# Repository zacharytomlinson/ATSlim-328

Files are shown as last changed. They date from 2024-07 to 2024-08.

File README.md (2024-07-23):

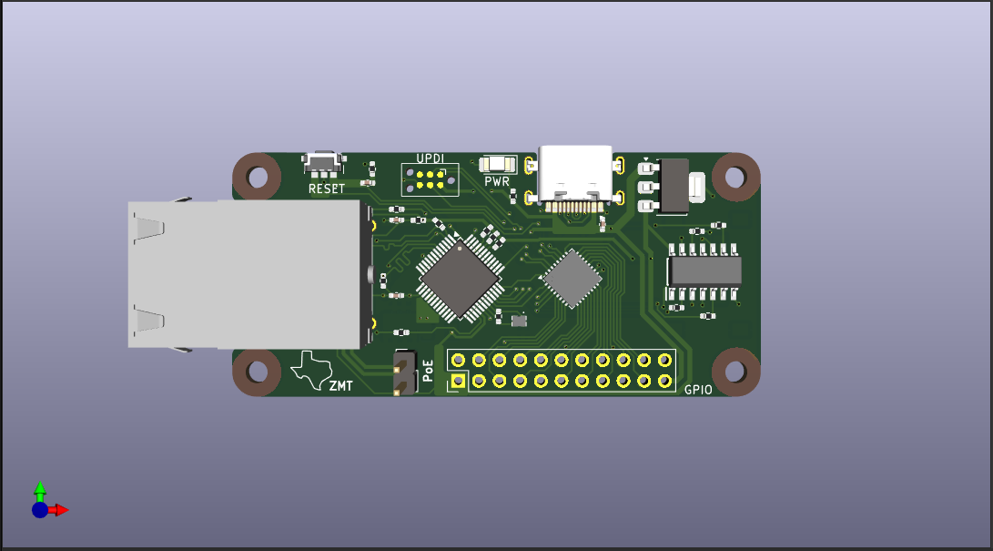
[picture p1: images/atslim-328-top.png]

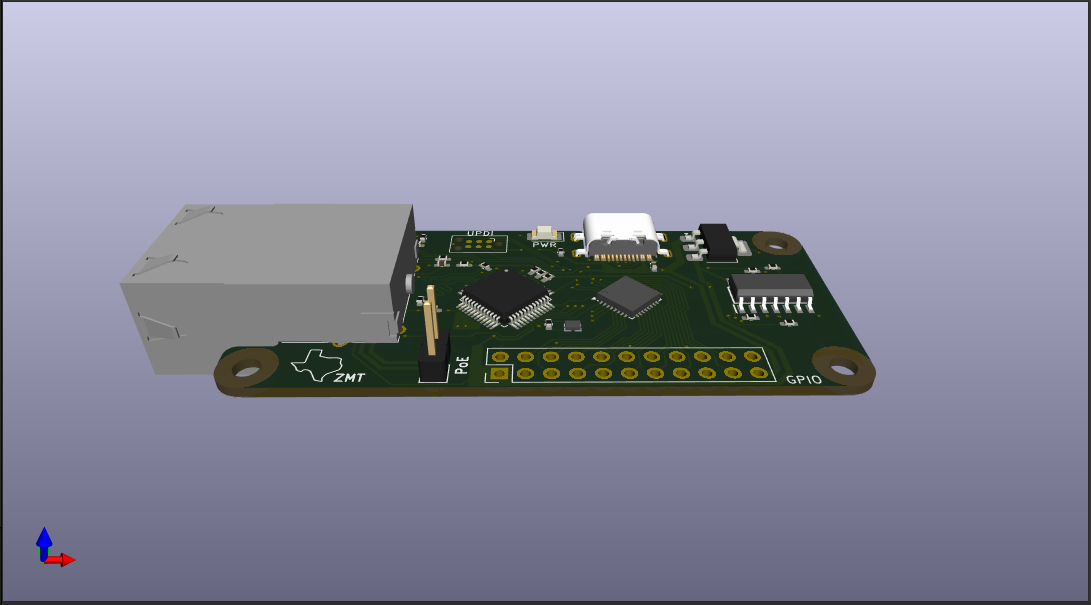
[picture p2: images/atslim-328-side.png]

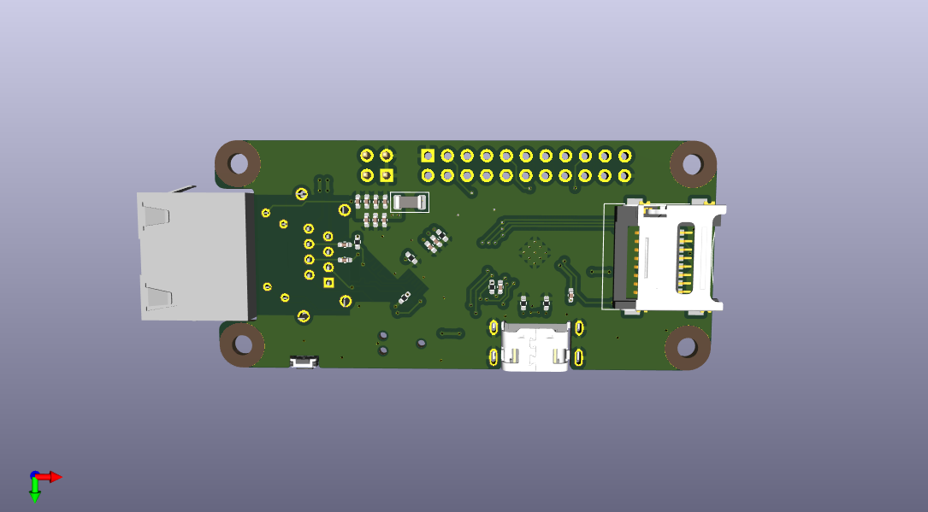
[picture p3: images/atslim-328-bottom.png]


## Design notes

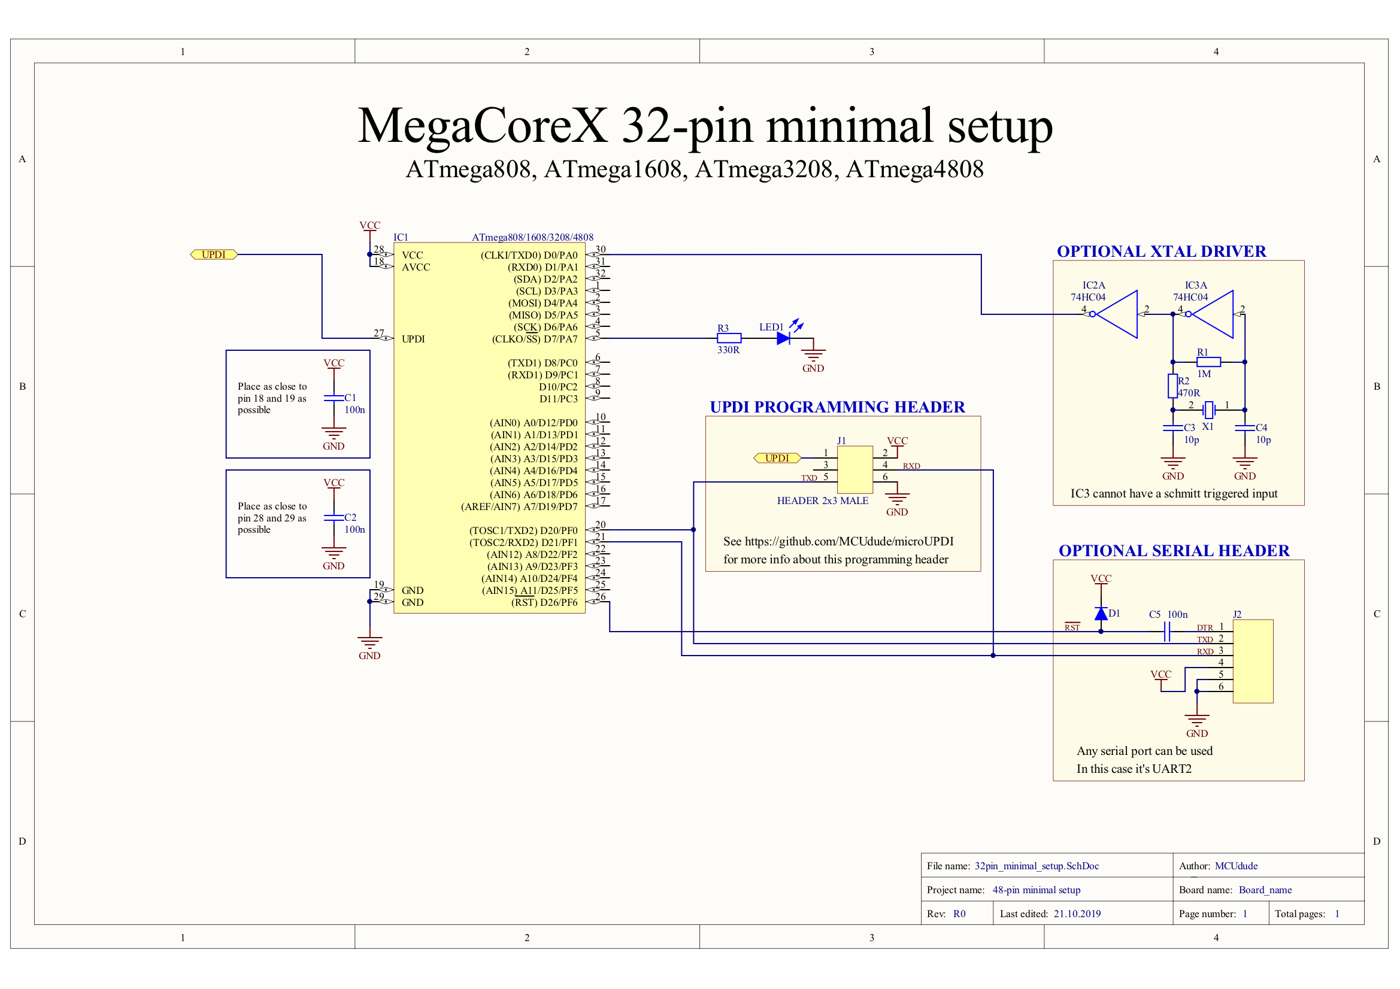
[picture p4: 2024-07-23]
fiducials/doc/3208PinDesc.png

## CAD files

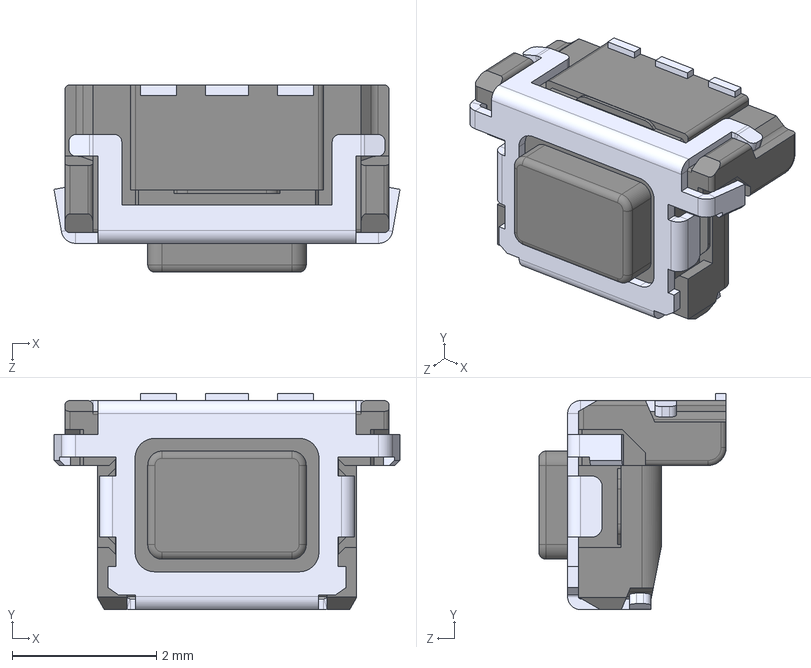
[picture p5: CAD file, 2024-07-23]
fiducials/3D/EVP-AEDB2A.step
4.80 x 3.00 x 2.60 mm

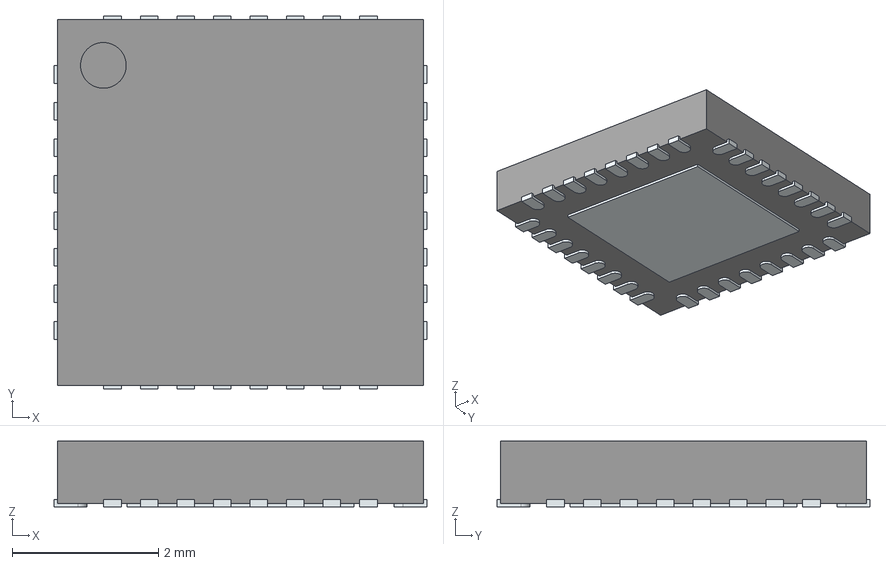
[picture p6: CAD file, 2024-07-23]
fiducials/3D/ATMEGA3208-MFR.stp
5.10 x 5.10 x 0.9 mm
ThermalPin
PinsArrayLR
PinsArrayTB

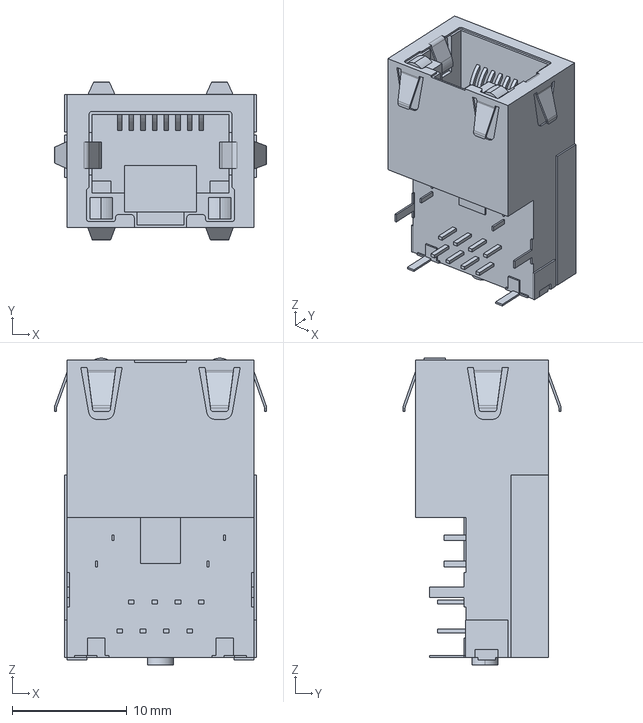
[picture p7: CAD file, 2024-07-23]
fiducials/3D/1888250-1.stp
18.5 x 13.8 x 26.7 mm

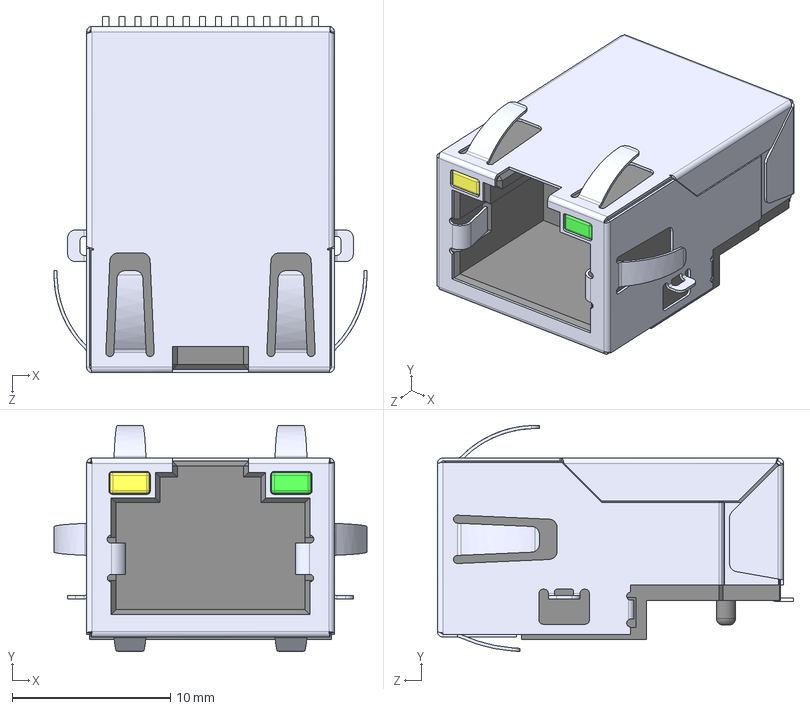
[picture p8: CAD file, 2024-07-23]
fiducials/3D/7498111120R.step
19.7 x 14.3 x 22.5 mm

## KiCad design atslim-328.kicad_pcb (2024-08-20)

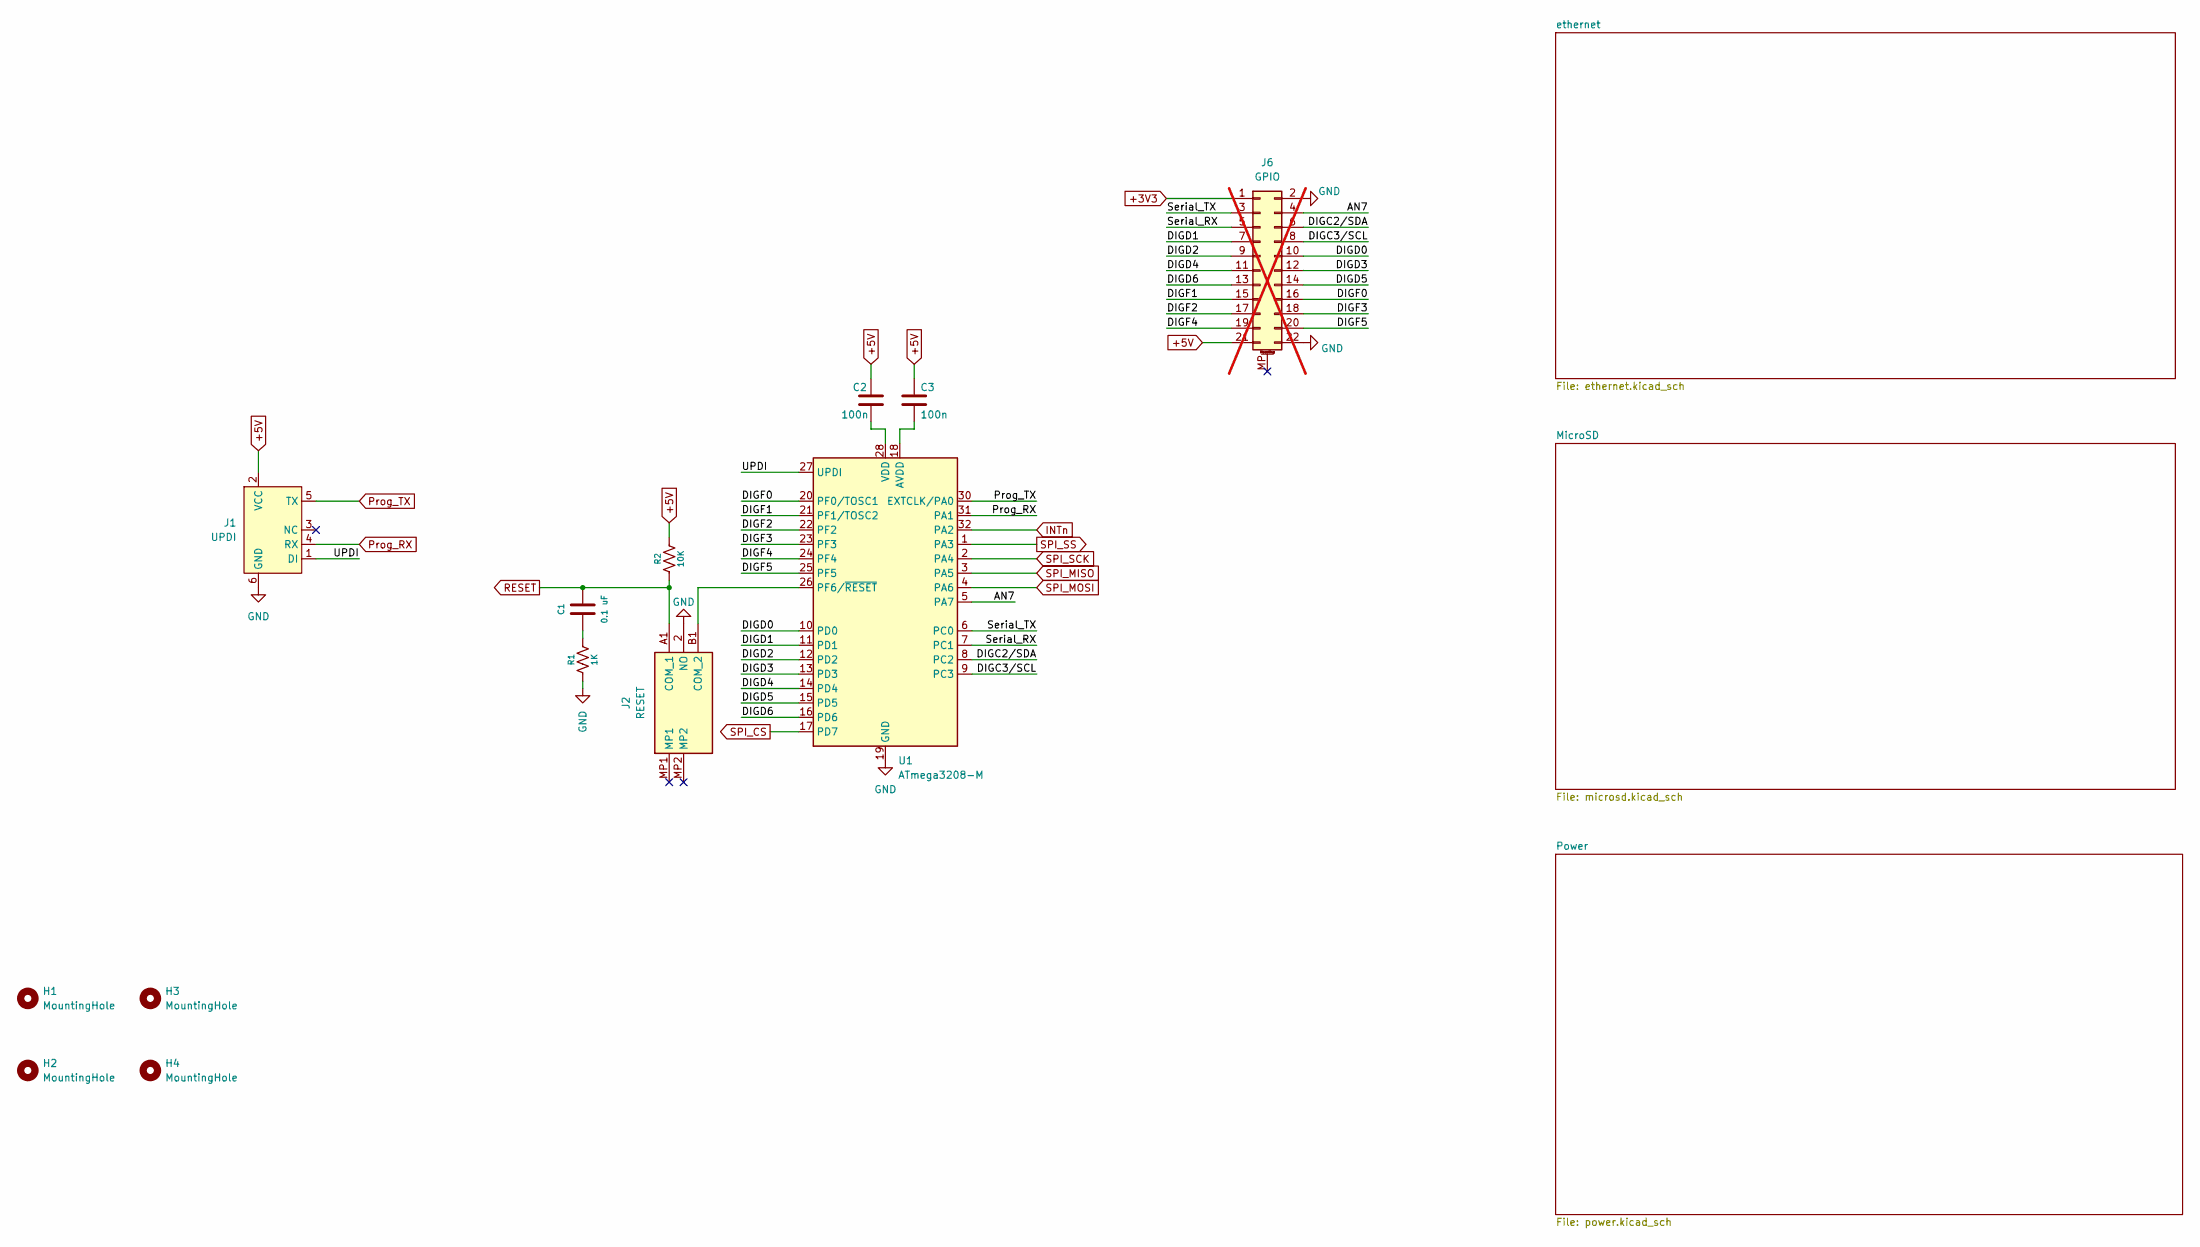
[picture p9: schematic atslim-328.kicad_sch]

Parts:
C1: 0.1 uF; C_0402_1005Metric_Pad0.74x0.62mm_HandSolder; MPN C0805C104K1RACAUTO
C2, C3: 100n; C_0402_1005Metric_Pad0.74x0.62mm_HandSolder
H1, H2, H3, H4: MountingHole; RPI_MountingHole
J1: UPDI; Tag-Connect_TC2030-IDC-NL_2x03_P1.27mm_Vertical
J2: RESET; EVPAEDB2A; Mouser Part Number 667-EVP-AEDB2A
J6: GPIO; PinHeader_2x11_P2.54mm_Vertical; not fitted
R1: 1K; R_0402_1005Metric_Pad0.72x0.64mm_HandSolder; MPN CRCW08051K00JNEA
R2: 10K; R_0402_1005Metric_Pad0.72x0.64mm_HandSolder; MPN CRCW080510K0JNEA
U1: ATmega3208-M; QFN-32-1EP_5x5mm_P0.5mm_EP3.1x3.1mm_ThermalVias

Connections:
+3V3: J6.1; also elsewhere on the board
+5V: C2.1, C3.1, J1.2 (VCC), J6.21, R2.2; also elsewhere on the board
/AN7: J6.4, U1.5 (PA7)
/DIGC2/SDA: J6.6, U1.8 (PC2)
/DIGC3/SCL: J6.8, U1.9 (PC3)
/DIGD0: J6.10, U1.10 (PD0)
/DIGD1: J6.7, U1.11 (PD1)
/DIGD2: J6.9, U1.12 (PD2)
/DIGD3: J6.12, U1.13 (PD3)
/DIGD4: J6.11, U1.14 (PD4)
/DIGD5: J6.14, U1.15 (PD5)
/DIGD6: J6.13, U1.16 (PD6)
/DIGF0: J6.16, U1.20 (PF0/TOSC1)
/DIGF1: J6.15, U1.21 (PF1/TOSC2)
/DIGF2: J6.17, U1.22 (PF2)
/DIGF3: J6.18, U1.23 (PF3)
/DIGF4: J6.19, U1.24 (PF4)
/DIGF5: J6.20, U1.25 (PF5)
/Serial_RX: J6.5, U1.7 (PC1)
/Serial_TX: J6.3, U1.6 (PC0)
/UPDI: J1.1 (DI), U1.27 (UPDI)
GND: J1.6 (GND), J2.2 (NO), J6.2, J6.22, R1.1, U1.19 (GND), U1.29 (GND), U1.33 (GND); also elsewhere on the board
INTn: U1.32 (PA2); also elsewhere on the board
unnamed: C1.1, R1.2
unnamed: J2.B1 (COM_2), U1.26 (PF6/~RESET)
unnamed: C3.2, U1.18 (AVDD)
unnamed: C2.2, U1.28 (VDD)
Prog_RX: J1.4 (RX), U1.31 (PA1)
Prog_TX: J1.5 (TX), U1.30 (EXTCLK/PA0)
RESET: C1.2, J2.A1 (COM_1), R2.1; also elsewhere on the board
SPI_CS: U1.17 (PD7); also elsewhere on the board
SPI_MISO: U1.3 (PA5); also elsewhere on the board
SPI_MOSI: U1.4 (PA6); also elsewhere on the board
SPI_SCK: U1.2 (PA4); also elsewhere on the board
SPI_SS: U1.1 (PA3); also elsewhere on the board

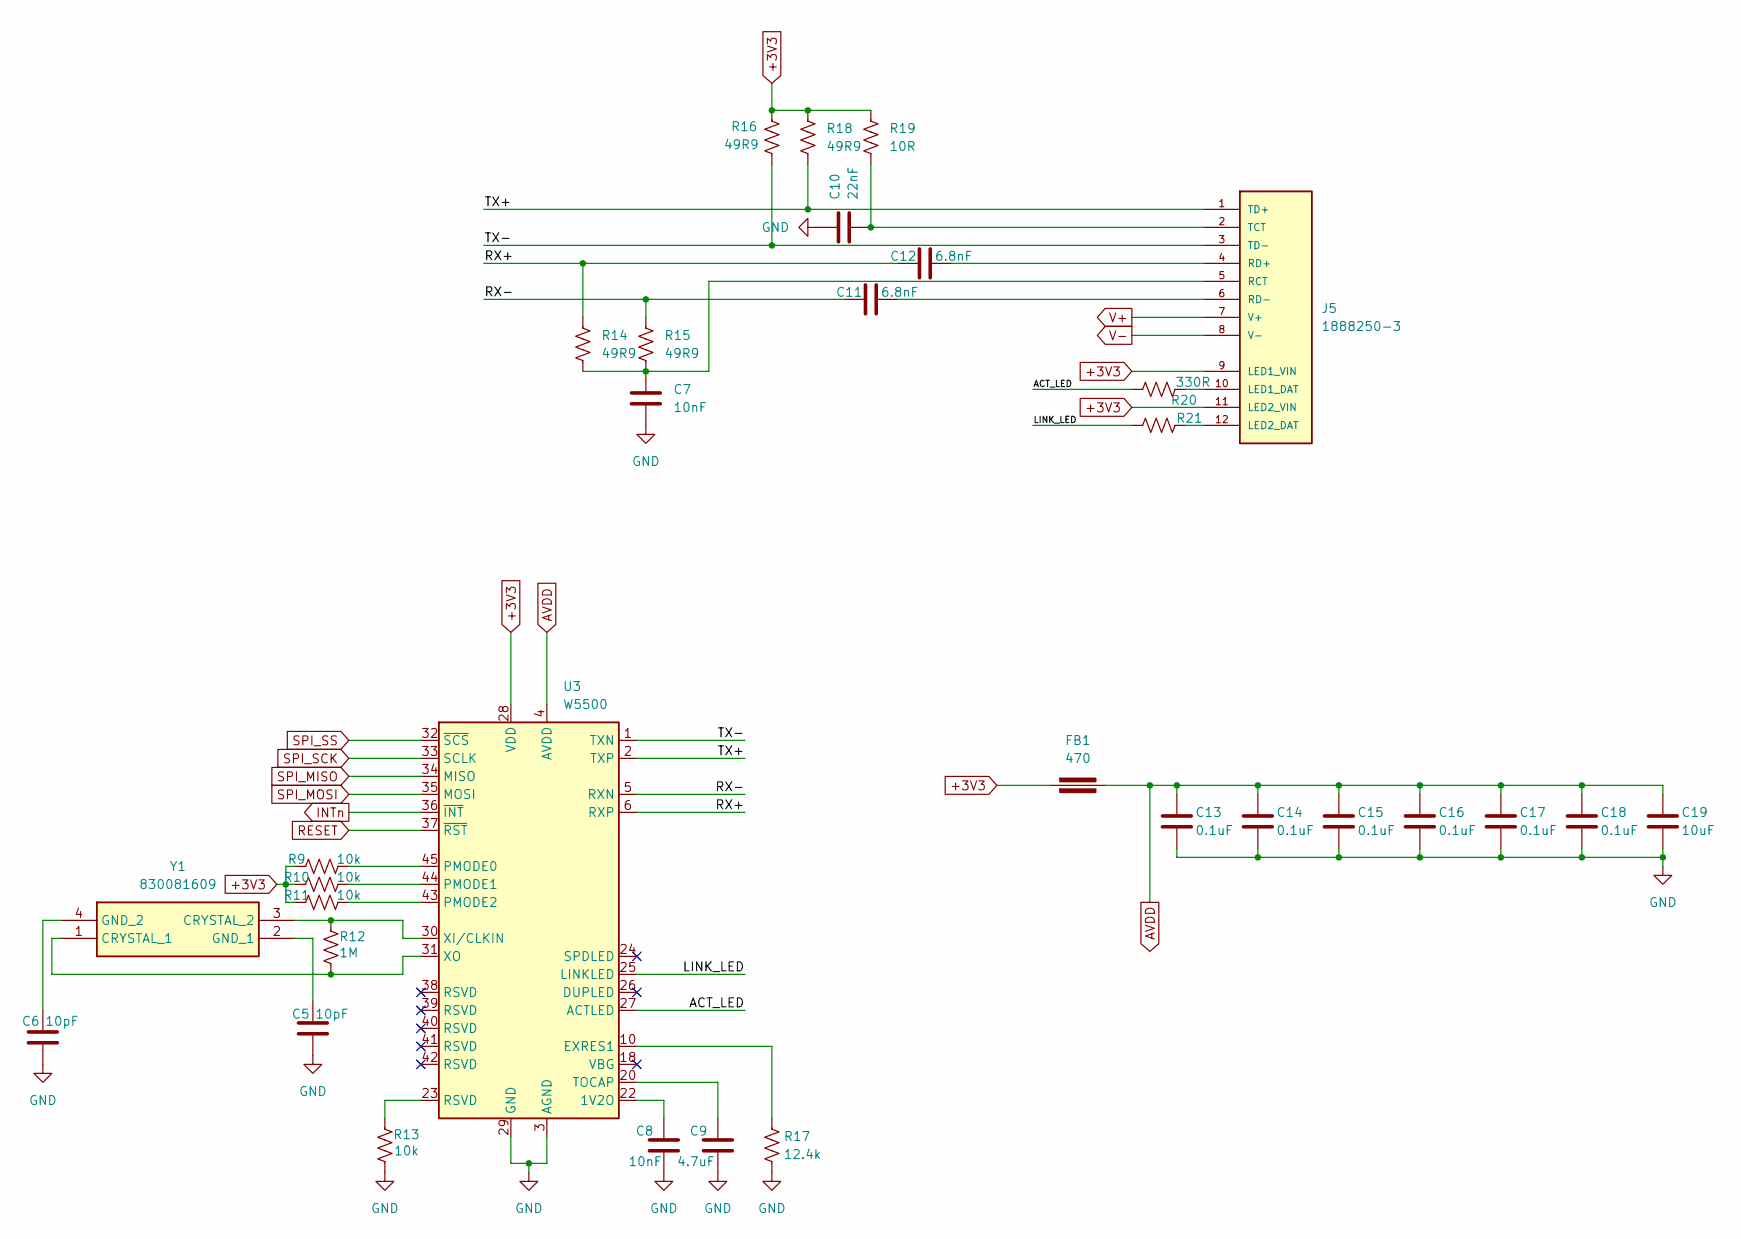
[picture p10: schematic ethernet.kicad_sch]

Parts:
C5, C6: 10pF; C_0402_1005Metric_Pad0.74x0.62mm_HandSolder
C7, C8: 10nF; C_0402_1005Metric_Pad0.74x0.62mm_HandSolder
C9: 4.7uF; C_0402_1005Metric_Pad0.74x0.62mm_HandSolder
C10: 22nF; C_0402_1005Metric_Pad0.74x0.62mm_HandSolder
C11, C12: 6.8nF; C_0402_1005Metric_Pad0.74x0.62mm_HandSolder
C13, C14, C15, C16, C17, C18: 0.1uF; C_0402_1005Metric_Pad0.74x0.62mm_HandSolder
C19: 10uF; C_0402_1005Metric_Pad0.74x0.62mm_HandSolder
FB1: 470; Ferrite_1206_3216Metric
J5: 1888250-3; TE_1888250-3; PARTREV D
R9, R10, R11, R13: 10k; R_0402_1005Metric_Pad0.72x0.64mm_HandSolder
R12: 1M; R_0402_1005Metric_Pad0.72x0.64mm_HandSolder
R14, R15, R16, R18: 49R9; R_0402_1005Metric_Pad0.72x0.64mm_HandSolder
R17: 12.4k; R_0402_1005Metric_Pad0.72x0.64mm_HandSolder
R19: 10R; R_0402_1005Metric_Pad0.72x0.64mm_HandSolder
R20, R21: 330R; R_0402_1005Metric_Pad0.72x0.64mm_HandSolder
U3: W5500; LQFP-48_7x7mm_P0.5mm
Y1: 830081609; Manufacturer_Part_Number 830081609

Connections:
+3V3: FB1.1, J5.9 (LED1_VIN), J5.11 (LED2_VIN), R9.2, R10.2, R11.2, R16.1, R18.1, R19.1, U3.28 (VDD); also elsewhere on the board
/ethernet/ACT_LED: R20.2, U3.27 (ACTLED)
/ethernet/LINK_LED: R21.2, U3.25 (LINKLED)
/ethernet/RX+: C12.2, R14.1, U3.6 (RXP)
/ethernet/RX-: C11.2, R15.1, U3.5 (RXN)
/ethernet/TX+: J5.1 (TD+), R18.2, U3.2 (TXP)
/ethernet/TX-: J5.3 (TD-), R16.2, U3.1 (TXN)
AVDD: C13.1, C14.1, C15.1, C16.1, C17.1, C18.1, C19.1, FB1.2, U3.4 (AVDD), U3.8 (AVDD), U3.11 (AVDD), U3.15 (AVDD), U3.17 (AVDD), U3.21 (AVDD)
GND: C5.2, C6.2, C7.2, C8.2, C9.2, C10.1, C13.2, C14.2, C15.2, C16.2, C17.2, C18.2, C19.2, R13.1, R17.1, U3.3 (AGND), U3.9 (AGND), U3.14 (AGND), U3.16 (AGND), U3.19 (AGND), U3.29 (GND), U3.48 (AGND); also elsewhere on the board
INTn: U3.36 (~INT); also elsewhere on the board
unnamed: J5.10 (LED1_DAT), R20.1
unnamed: J5.12 (LED2_DAT), R21.1
unnamed: C7.1, J5.5 (RCT), R14.2, R15.2
unnamed: C12.1, J5.4 (RD+)
unnamed: C11.1, J5.6 (RD-)
unnamed: C10.2, J5.2 (TCT), R19.2
unnamed: R13.2, U3.23 (RSVD)
unnamed: C8.1, U3.22 (1V2O)
unnamed: R17.2, U3.10 (EXRES1)
unnamed: R9.1, U3.45 (PMODE0)
unnamed: R10.1, U3.44 (PMODE1)
unnamed: R11.1, U3.43 (PMODE2)
unnamed: C9.1, U3.20 (TOCAP)
unnamed: R12.2, U3.30 (XI/CLKIN), Y1.3 (CRYSTAL_2)
unnamed: R12.1, U3.31 (XO), Y1.1 (CRYSTAL_1)
unnamed: C5.1, Y1.2 (GND_1)
unnamed: C6.1, Y1.4 (GND_2)
RESET: U3.37 (~RST); also elsewhere on the board
SPI_MISO: U3.34 (MISO); also elsewhere on the board
SPI_MOSI: U3.35 (MOSI); also elsewhere on the board
SPI_SCK: U3.33 (SCLK); also elsewhere on the board
SPI_SS: U3.32 (~SCS); also elsewhere on the board
V+: J5.7 (V+); also elsewhere on the board
V-: J5.8 (V-); also elsewhere on the board

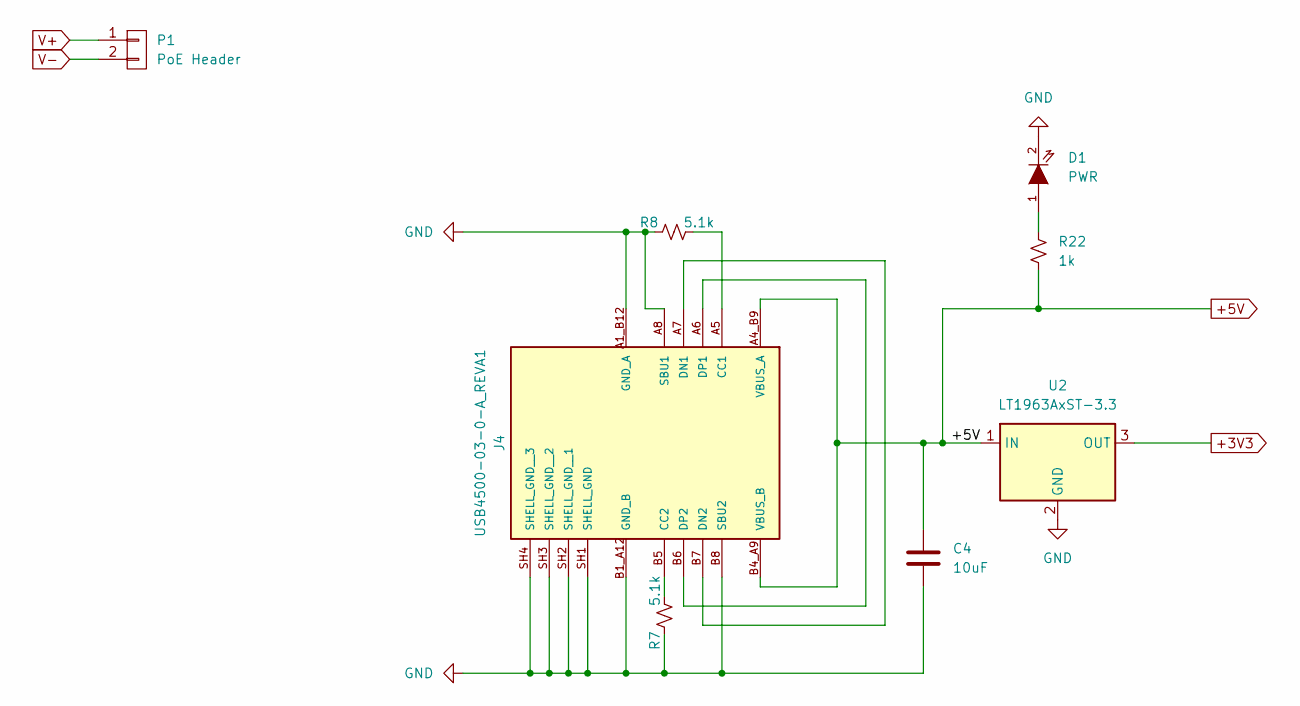
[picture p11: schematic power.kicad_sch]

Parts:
C4: 10uF; C_0402_1005Metric_Pad0.74x0.62mm_HandSolder
D1: PWR; LED_1206_3216Metric_Pad1.42x1.75mm_HandSolder
J4: USB4500-03-0-A_REVA1; GCT_USB4500-03-0-A_REVA1; PARTREV A1
P1: PoE Header; PinHeader_1x02_P2.54mm_Vertical
R7, R8: 5.1k; R_0402_1005Metric_Pad0.72x0.64mm_HandSolder
R22: 1k; R_0402_1005Metric_Pad0.72x0.64mm_HandSolder
U2: LT1963AxST-3.3; SOT-223-3_TabPin2

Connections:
+3V3: U2.3 (OUT); also elsewhere on the board
+5V: C4.1, J4.A4_B9 (VBUS_A), J4.B4_A9 (VBUS_B), R22.2, U2.1 (IN); also elsewhere on the board
GND: C4.2, D1.2 (K), J4.A1_B12 (GND_A), J4.A8 (SBU1), J4.B1_A12 (GND_B), J4.B8 (SBU2), J4.SH1 (SHELL_GND), J4.SH2 (SHELL_GND__1), J4.SH3 (SHELL_GND__2), J4.SH4 (SHELL_GND__3), R7.1, R8.1, U2.2 (GND); also elsewhere on the board
unnamed: D1.1 (A), R22.1
unnamed: J4.A5 (CC1), R8.2
unnamed: J4.B5 (CC2), R7.2
unnamed: J4.A7 (DN1), J4.B7 (DN2)
unnamed: J4.A6 (DP1), J4.B6 (DP2)
V+: P1.1; also elsewhere on the board
V-: P1.2; also elsewhere on the board

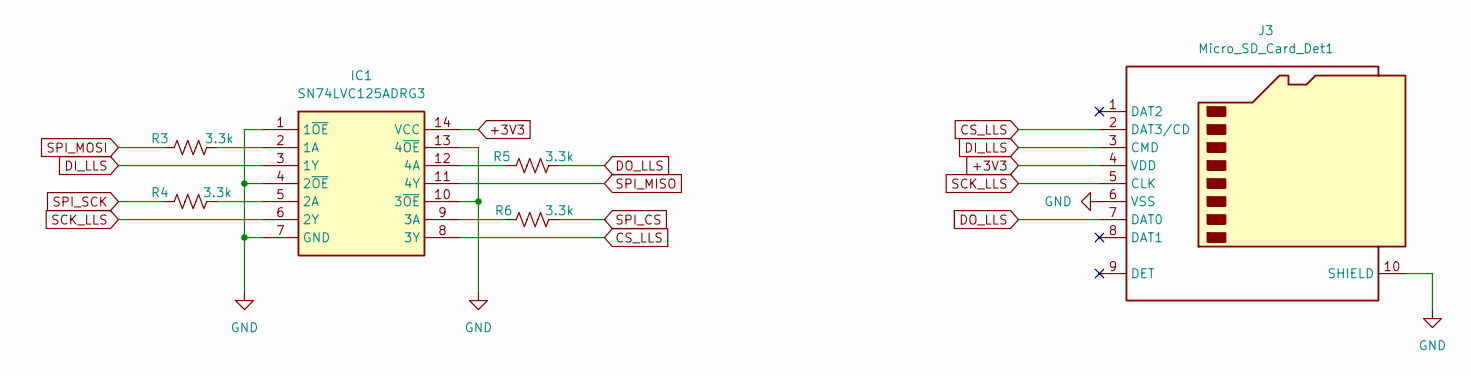
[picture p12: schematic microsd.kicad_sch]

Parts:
IC1: SN74LVC125ADRG3; SOIC127P600X175-14N; Mouser Part Number 595-SN74LVC125ADRG3
J3: Micro_SD_Card_Det1; microSD_HC_Wuerth_693072010801
R3, R4, R5, R6: 3.3k; R_0402_1005Metric_Pad0.72x0.64mm_HandSolder

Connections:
+3V3: IC1.14 (VCC), J3.4 (VDD); also elsewhere on the board
CS_LLS: IC1.8 (3Y), J3.2 (DAT3/CD)
DI_LLS: IC1.3 (1Y), J3.3 (CMD)
DO_LLS: J3.7 (DAT0), R5.2
GND: IC1.1 (1~OE), IC1.4 (2~OE), IC1.7 (GND), IC1.10 (3~OE), IC1.13 (4~OE), J3.6 (VSS), J3.10 (SHIELD); also elsewhere on the board
unnamed: IC1.2 (1A), R3.2
unnamed: IC1.5 (2A), R4.2
unnamed: IC1.9 (3A), R6.1
unnamed: IC1.12 (4A), R5.1
SCK_LLS: IC1.6 (2Y), J3.5 (CLK)
SPI_CS: R6.2; also elsewhere on the board
SPI_MISO: IC1.11 (4Y); also elsewhere on the board
SPI_MOSI: R3.1; also elsewhere on the board
SPI_SCK: R4.1; also elsewhere on the board

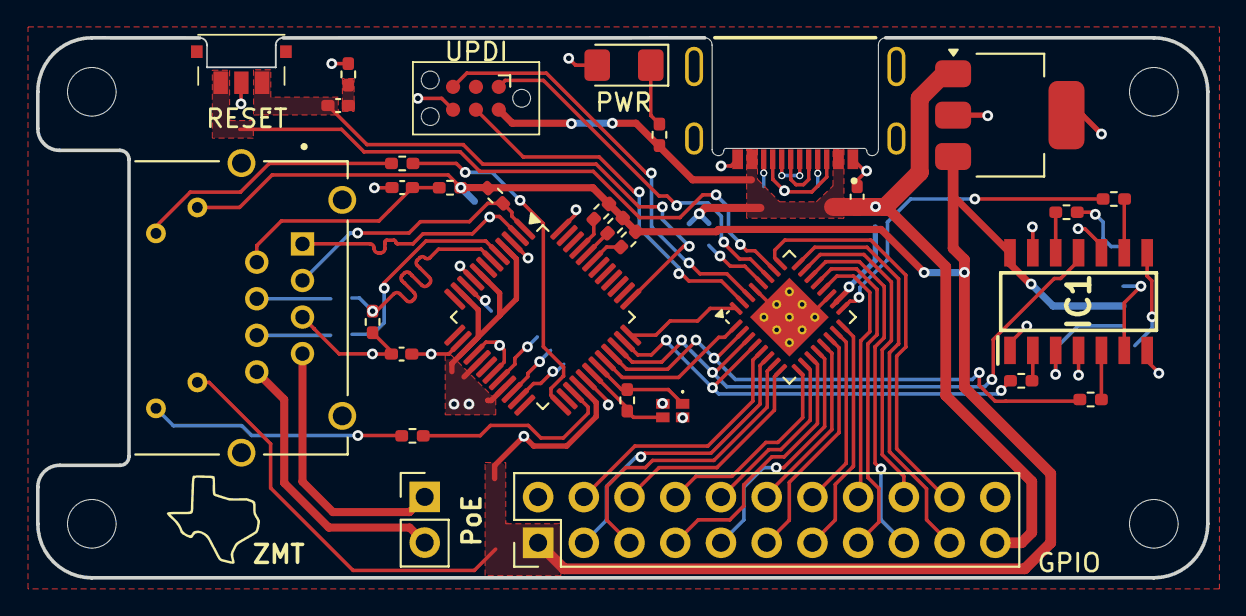
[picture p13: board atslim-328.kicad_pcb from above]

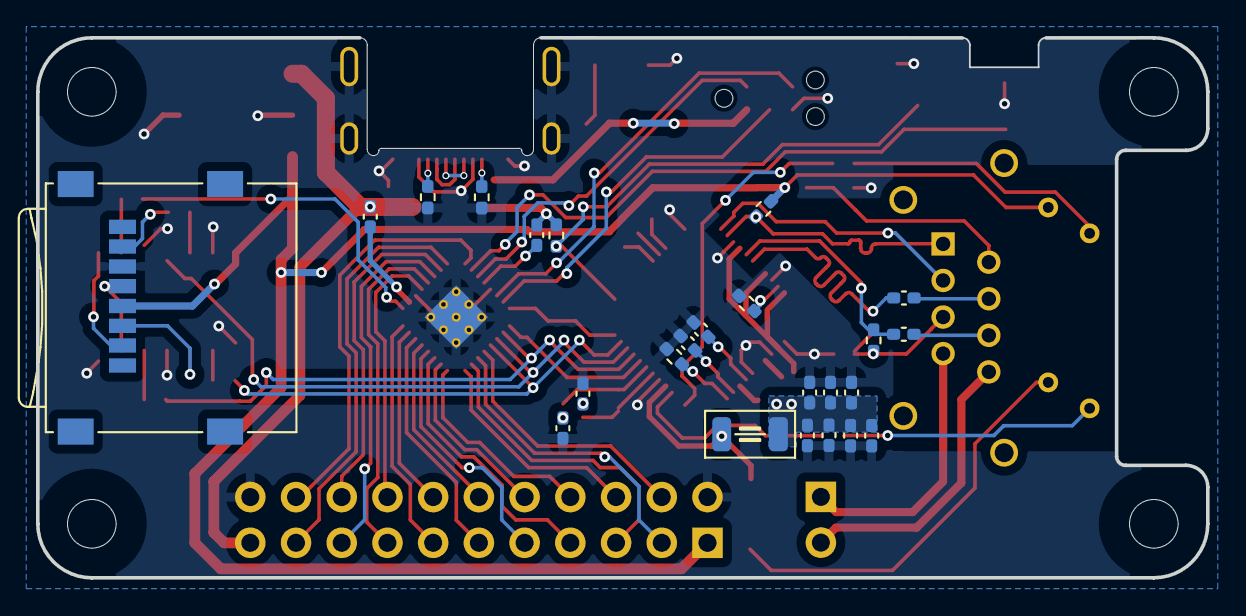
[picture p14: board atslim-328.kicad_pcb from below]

Board: 2 copper layers, 65.0 x 30.0 mm, 59 parts (24 on the bottom side), 74 nets.

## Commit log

2024-07-23 Reinit without temp files
    [1888250-1.stp, 7498111120R.step, ATMEGA3208-MFR.stp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]
2024-07-23 Added imgs of 3D view
    [atslim-328.kicad_pcb]
2024-07-23 Cleanup and added PoE header
    [atslim-328.kicad_pcb, ethernet.kicad_sch, power.kicad_sch]
2024-07-23 Sent off to manufacturer for test articles
    [atslim-328-CuBottom.gbr, atslim-328-CuTop.gbr, atslim-328-EdgeCuts.gbr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]
2024-07-23 update gitignore for a couple of manufacturing artifacts
2024-08-16 Recent updates
    [atslim-328.kicad_pcb, atslim-328.kicad_sch, ethernet.kicad_sch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]
2024-08-20 Fucked up UPDI... of course
    [atslim-328.kicad_pcb, atslim-328.kicad_sch]
